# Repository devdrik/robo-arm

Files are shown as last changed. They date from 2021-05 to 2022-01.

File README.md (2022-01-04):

# robo arm

https://user-images.githubusercontent.com/67547895/148030076-b6884d7a-699d-42de-8d19-b7936f6b32be.mp4

This repo is all about the little robo arm. The community named it **Serworm Michael**, so that is his name now. The arm has a very simple structure, but still enough DoFs to make it a fun challenge to work with. The structure can be 3D printed. The servos are Dynamixel XL330-M288-T. There should be everything you need in this repo. If not, please let me know! 

The project is work in progress, but it already works. I am very happy, if you add features, refactor the code or point out bad practices. Feel free to open an issue, a pull-request or contact me.

You can find a more detailed (german) description here: [devdrik.de/robo-arm](https://devdrik.de/robo-arm/)

And here is a video about the desgin and assembly: https://youtu.be/1fdFsHWkn9U

## Material

You wont need much, but you need something for this robo. Here is a list:
* 1 Arduino MKR
* 1 DYNAMIXEL Shield for Arduino MKR
* 5 DYNAMIXEL-XL330-M288-T
* 1 Raspberry Pi
* USB-a to micro USB cable
* A 3D-Printer could help

Find product links here: [devdrik.de/hardware-von-serworm-michael](https://devdrik.de/hardware-von-serworm-michael/)

## Setup

### Arduino
Nothing to setup here. Just flash dynamixel_api from the code/arduino folder to your Arduino and you are all set.

### Python environment

You need a python3 environment with pip installed in order to get the robo arm to work. In that env you need to install [ikpy](https://github.com/Phylliade/ikpy). You only need ikpy, if you intend to use inverse kinematics.
```
pip install ikpy
```

### 3D prints

The files to print can be found in the cad section. They should be easy prints, nothing special here. 
You will need:
* 1 base.stl (clamp to table)
* 1 base_element.stl (screwed to base servo)
* 4 arm_element.stl

## Build the bot

Building the robo arm is very easy! 
Put a servo in the base, screw the base_element on that. Then screw the arm_elements to it one after another. done!
You can use the screws shipped with the servos.
Make sure to clamp the base to a table or something solid, otherwise the arm will fall :(

## Configuration

You need to define the serial device in ```main.py```. This device is the arduino with the API.

## Usage

There is not yet a GUI or any other interface. You need to open the main file and write some code in order to get results. The easiest way is to comment in an example. Usually you want to use the API of robo.py to interact with the arm and the API of inversekinematics.py to calculate the input (angles) for the robo API.

You can also use the `teachposition` function to get a little cli and teach the arm some positions and save those for later.

There might be some helpful (german) articles on my blog: [devdrik.de/robo-arm](https://devdrik.de/robo-arm/)

# HAVE FUN!

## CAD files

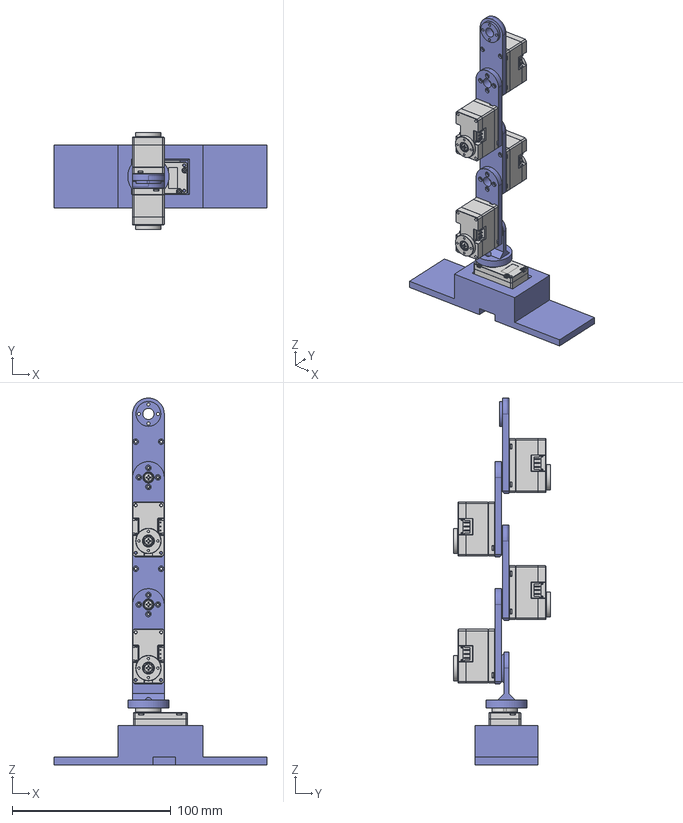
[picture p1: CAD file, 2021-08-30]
cad/roboArm.step
133.8 x 61.3 x 231.0 mm
ARM_4 x 4
DC15_A01_CASE_M_DUMMY x 5
DC15_A01_CASE_F_DUMMY x 5
DC15_A01_CASE_B_DUMMY x 5
DC15_A01_HORN_DUMMY x 5
DC15_A01_LED_CAP2_DUMMY x 5
PHS_1_7X20_5_DC10 x 20
BTS2_M2_6X8 x 10
DC15_A01_HORN_IDLE2_DUMMY x 5
DC15_A01_IDLE_CAP_DUMMY x 5
B3B-EH x 10

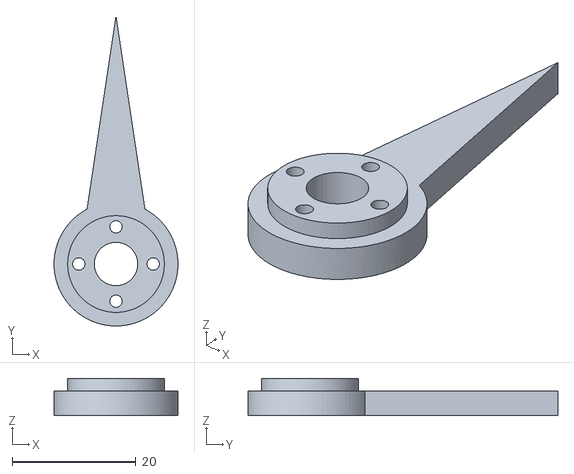
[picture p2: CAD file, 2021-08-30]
cad/clock_tip.stl
20.0 x 50.0 x 6.00

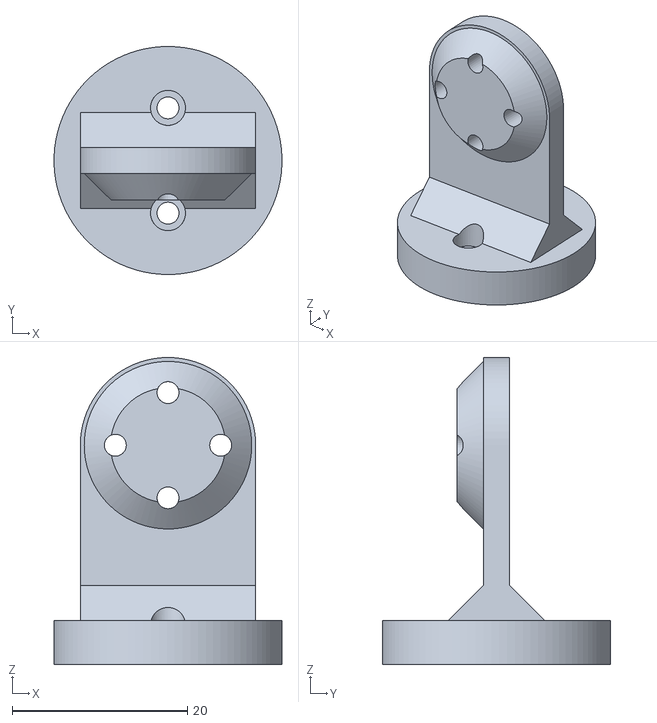
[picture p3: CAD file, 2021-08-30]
cad/base_element.stl
26.0 x 26.0 x 35.0

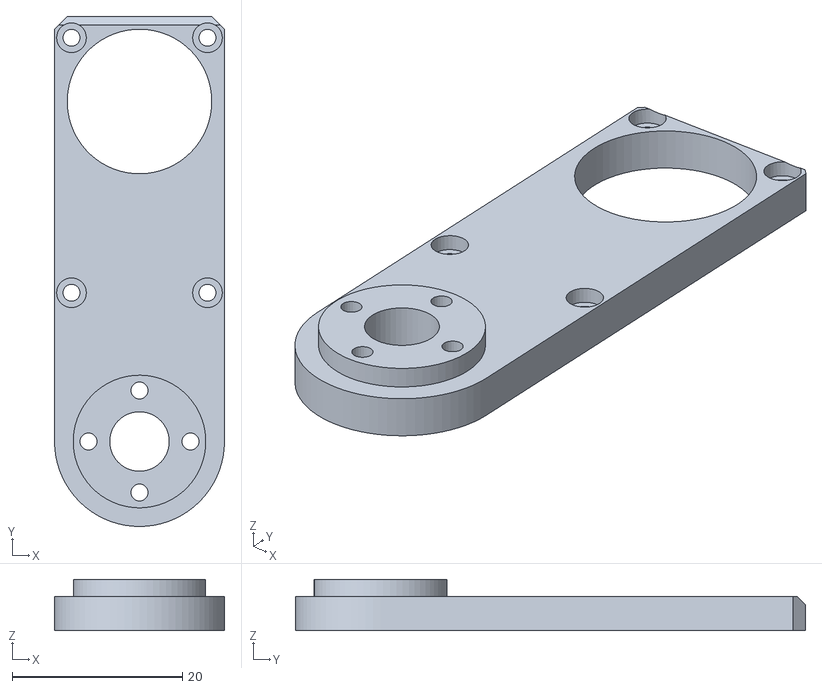
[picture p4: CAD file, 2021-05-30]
cad/arm_element.stl
20.0 x 60.0 x 6.00

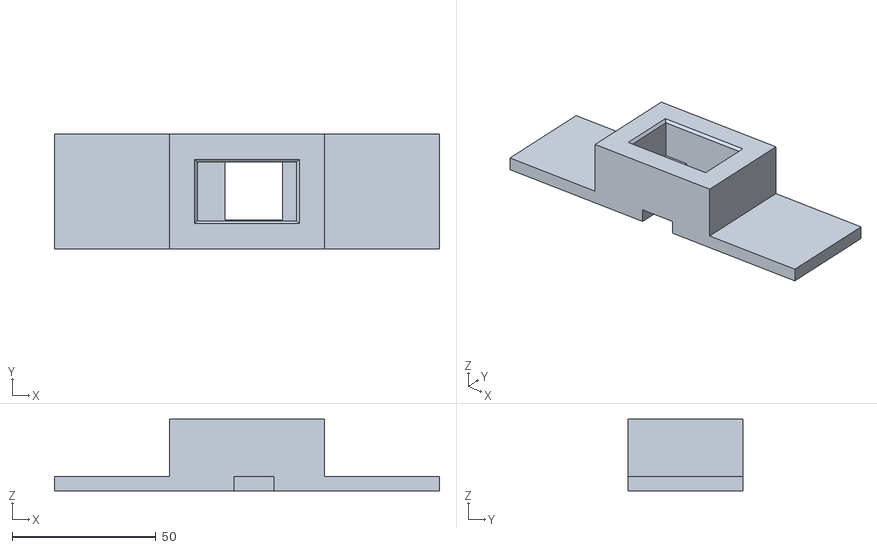
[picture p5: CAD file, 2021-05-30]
cad/base.stl
133.8 x 39.8 x 25.0

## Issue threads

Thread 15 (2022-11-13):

Building rotating  mini robot

ibnbax, 2022-11-13:
Can you make  rotating  robot  wich cant rotate phone for example and camera to take pictures
for the the phone  and how much ot will cost?

devdrik, 2022-11-16:
If you only want rotation around one axis, that should not be a problem, but you won't need a full arm for that either. If you want a full arm that is capable of holding a phone you are probably better off buying a commercial product.

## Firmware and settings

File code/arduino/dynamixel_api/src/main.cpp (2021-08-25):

/*******************************************************************************
* Copyright 2016 ROBOTIS CO., LTD.
*
* Licensed under the Apache License, Version 2.0 (the "License");
* you may not use this file except in compliance with the License.
* You may obtain a copy of the License at
*
*     http://www.apache.org/licenses/LICENSE-2.0
*
* Unless required by applicable law or agreed to in writing, software
* distributed under the License is distributed on an "AS IS" BASIS,
* WITHOUT WARRANTIES OR CONDITIONS OF ANY KIND, either express or implied.
* See the License for the specific language governing permissions and
* limitations under the License.
*******************************************************************************/

#include <DynamixelShield.h>

#define DEBUG_SERIAL Serial
#define DATA_SERIAL Serial
#define SERIAL_BAUD 115200

#define DEBUG false

const float DXL_PROTOCOL_VERSION = 2.0;
const uint8_t servosIDs[] = {0,1,2,3,4,11};
// the size of goalAngles should equal the highest servoID+1. This makes it easy to use the servoId as index to access goalAngles
float goalAngles[] = {0,0,0,0,0,0,0,0,0,0,0,0};

DynamixelShield dxl;


const char separator = ':';
const char msgEndChar = '\n';
#define FUNC_SET_ANGLE 1
#define FUNC_GET_ANGLE 2
#define FUNC_SET_ANGLE_FOUR 3
#define FUNC_SET_PROFILE_VELOCITY 4
#define FUNC_SET_PROFILE_VELOCITY_ALL 5
#define FUNC_HAS_REACHED_ANGLE 6
#define FUNC_SET_POSITION_MODE_ALL 7
#define FUNC_TORQUE_OFF_ALL 8
#define FUNC_IS_MOVING 9


//This namespace is required to use Control table item names
using namespace ControlTableItem;



void setAngle(u_int8_t servoId, float angle) {
  goalAngles[servoId] = angle;
  dxl.setGoalPosition(servoId, angle, UNIT_DEGREE);
}

float getAngle(u_int8_t servoId) {
  return dxl.getPresentPosition(servoId, UNIT_DEGREE);
}

void writeToControlTable(uint8_t servoID, uint8_t itemIdx, int32_t data) {
  dxl.torqueOff(servoID);
  dxl.writeControlTableItem(itemIdx, servoID, data);
  dxl.torqueOn(servoID);
}

void setProfileVelocity(uint8_t servoID, uint32_t velocity) {
  // 0-32767; 0 -> max speed
  writeToControlTable(servoID, PROFILE_VELOCITY, velocity);
}

void setProfileVelocityAll(uint32_t velocity) {
  for (uint8_t id : servosIDs) {
    writeToControlTable(id, PROFILE_VELOCITY, velocity);
  }
}

bool hasReachedGoalAngle(uint8_t servoId) {
  delay(50);
  int moving_status = dxl.readControlTableItem(MOVING_STATUS, servoId);
  // DEBUG_SERIAL.print("moving_status: ");
  // DEBUG_SERIAL.println(moving_status, BIN);
  int mask = 3;
  return (moving_status & mask) == 1;
  // float offset = 3;
  // float currentAngle = getAngle(servoId);
  // return currentAngle >= goalAngles[servoId] - offset &&
  //         currentAngle <= goalAngles[servoId] + offset;
}

void setOperatingMode(uint8_t servoID, uint8_t mode) {
  dxl.torqueOff(servoID);
  dxl.setOperatingMode(servoID, mode);
  dxl.torqueOn(servoID);
}

void torqueOff(uint8_t servoID) {
  dxl.torqueOff(servoID);
}

void floatToByte(byte* arr, float value) {
      long l = *(long*) &value;

      arr[0] = l & 0x00FF;
      arr[1] = (l >> 8) & 0x00FF;
      arr[2] = (l >> 16) & 0x00FF;
      arr[3] = l >> 24;
}

bool isMoving(uint8_t servoID) {
  int moving_status = dxl.readControlTableItem(MOVING_STATUS, servoID);
  int mask = 2;
  return (moving_status & mask) > 0;
}

void setup() {
  // put your setup code here, to run once:
  
  // For Uno, Nano, Mini, and Mega, use UART port of DYNAMIXEL Shield to debug.
  DATA_SERIAL.begin(SERIAL_BAUD);
  // while(!DEBUG_SERIAL);
  // if (DATA_SERIAL != DEBUG_SERIAL) {
  //   DEBUG_SERIAL.begin(SERIAL_BAUD);
  // }

  // Set Port baudrate to 57600bps. This has to match with DYNAMIXEL baudrate.
  dxl.begin(57600);
  // Set Port Protocol Version. This has to match with DYNAMIXEL protocol version.
  dxl.setPortProtocolVersion(DXL_PROTOCOL_VERSION);

  // Set all servos to position mode
  for(uint8_t servoID : servosIDs) {
    if(dxl.ping(servoID)) {
      dxl.torqueOff(servoID);
      dxl.setOperatingMode(servoID, OP_POSITION);
      dxl.writeControlTableItem(MOVING_THRESHOLD, servoID, 7);
      dxl.torqueOn(servoID);
      // DEBUG_SERIAL.print("Servo ");
      // DEBUG_SERIAL.print(servoID);
      // DEBUG_SERIAL.println(" set to Position Mode");
    } else {
      // DEBUG_SERIAL.print("Servo ");
      // DEBUG_SERIAL.print(servoID);
      // DEBUG_SERIAL.println(" not responding");
    }
  }

  // setProfileVelocity(0, 20);
  // setAngle(0, 1000);
  // while (!hasReachedGoalAngle(0))
  // {
  //   DEBUG_SERIAL.print("angle: ");
  //   DEBUG_SERIAL.println(getAngle(0));
  // }
  
  // DEBUG_SERIAL.print("done, angle: ");
  // DEBUG_SERIAL.println(getAngle(0));

  // setProfileVelocity(0, 20);
  // DEBUG_SERIAL.print("moving_threashold: ");
  // DEBUG_SERIAL.println(dxl.readControlTableItem(MOVING_THRESHOLD, 0));
  // setAngle(0, 20);
  // hasReachedGoalAngle(0);
  // delay(20);
  // hasReachedGoalAngle(0);
  // delay(20);
  // hasReachedGoalAngle(0);
  // delay(20);
  // hasReachedGoalAngle(0);
  // delay(20);
  // hasReachedGoalAngle(0);
  // delay(20);
  // hasReachedGoalAngle(0);
  // delay(20);
  // hasReachedGoalAngle(0);
  // delay(20);
  // hasReachedGoalAngle(0);
  // delay(20);
  // hasReachedGoalAngle(0);
  // delay(20);
  // hasReachedGoalAngle(0);
  // delay(20);
  // hasReachedGoalAngle(0);
  // delay(20);
  // hasReachedGoalAngle(0);
  // delay(20);
  // hasReachedGoalAngle(0);
  // delay(20);
  // hasReachedGoalAngle(0);
  // delay(20);
  // hasReachedGoalAngle(0);
  // delay(20);
  // hasReachedGoalAngle(0);
  // delay(20);
  // hasReachedGoalAngle(0);
  // delay(20);
  // hasReachedGoalAngle(0);
  // delay(20);
  // hasReachedGoalAngle(0);
  // delay(20);
  // hasReachedGoalAngle(0);
  // delay(20);
  // hasReachedGoalAngle(0);
  // delay(20);
  // hasReachedGoalAngle(0);
  // delay(20);
  // hasReachedGoalAngle(0);
  // delay(20);
  // hasReachedGoalAngle(0);
  // delay(20);
  // hasReachedGoalAngle(0);
  // delay(20);
  // // DEBUG_SERIAL.print("hasReached2: ");
  // // DEBUG_SERIAL.println(hasReachedGoalAngle(0));
  // // delay(100);
  // // DEBUG_SERIAL.print("hasReached3: ");
  // // DEBUG_SERIAL.println(hasReachedGoalAngle(0));
  // delay(10000);
  // DEBUG_SERIAL.println("delayed 10");
  // hasReachedGoalAngle(0);
  // // DEBUG_SERIAL.print("hasReached4: ");
  // // DEBUG_SERIAL.println(hasReachedGoalAngle(0));
  // // while (!hasReachedGoalAngle(0))
  // //   DEBUG_SERIAL.println("Im looping");
  // // {
  // // DEBUG_SERIAL.print("hasReached after: ");
  // // DEBUG_SERIAL.println(hasReachedGoalAngle(0));

  // delay(500);
  // setAngle(0, 1);
  // while (!hasReachedGoalAngle(0))
  // {
  //   DEBUG_SERIAL.print("angle: ");
  //   DEBUG_SERIAL.println(getAngle(0));
  // }

  // DEBUG_SERIAL.print("done, angle: ");
  // DEBUG_SERIAL.println(getAngle(0));

  
}
// FUNC:PARAM1:PARAMX\n

void loop() {

  if ( DATA_SERIAL.available() > 0 ) {
    uint8_t function = DATA_SERIAL.readStringUntil(separator).toInt();
    uint8_t id;
    float angle;
    uint32_t profileVelocity;

    switch (function)
    {
    case FUNC_SET_ANGLE:
      // FUNC:ID:ANGLE
      id = DATA_SERIAL.readStringUntil(separator).toInt();
      angle = DATA_SERIAL.readStringUntil(msgEndChar).toFloat();
      // Serial.print("Angle read and converted from string: ");
      // Serial.println(angle);
      setAngle(id, angle);
      break;
    
    case FUNC_GET_ANGLE:
      // FUNC:ID
      id = DATA_SERIAL.readStringUntil(msgEndChar).toInt();
      angle = getAngle(id);
      byte angleBytes[4];
      floatToByte(angleBytes, angle);
      DATA_SERIAL.write(angleBytes, 4);
      break;

    case FUNC_SET_ANGLE_FOUR:
    // FUNC:ANGLE1:ANGLE2:ANGLE3:ANGLE4
      setAngle(1, DATA_SERIAL.readStringUntil(separator).toFloat());
      setAngle(2, DATA_SERIAL.readStringUntil(separator).toFloat());
      setAngle(3, DATA_SERIAL.readStringUntil(separator).toFloat());
      setAngle(4, DATA_SERIAL.readStringUntil(msgEndChar).toFloat());
      break;

    case FUNC_SET_PROFILE_VELOCITY:
      // FUNC:ID:VELOCITY
      id = DATA_SERIAL.readStringUntil(separator).toInt();
      profileVelocity = DATA_SERIAL.readStringUntil(msgEndChar).toInt();
      setProfileVelocity(id, profileVelocity);
      break;

    case FUNC_SET_PROFILE_VELOCITY_ALL:
      // FUNC:VELOCITY
      profileVelocity = DATA_SERIAL.readStringUntil(msgEndChar).toInt();
      setProfileVelocityAll(profileVelocity);
      break;

    case FUNC_HAS_REACHED_ANGLE:
      // FUNC:ID
      id = DATA_SERIAL.readStringUntil(msgEndChar).toInt();
      bool hasReachedAngle;
      hasReachedAngle = hasReachedGoalAngle(id);
      byte hasReached;
      hasReached = hasReachedAngle ? (byte) 1 : (byte) 0;
      DATA_SERIAL.write(hasReached);
      break;

    case FUNC_SET_POSITION_MODE_ALL:
      // FUNC:ID
      id = DATA_SERIAL.readStringUntil(msgEndChar).toInt();
      setOperatingMode(id, OP_POSITION);
      break;

    case FUNC_TORQUE_OFF_ALL:
      // FUNC:ID
      id = DATA_SERIAL.readStringUntil(msgEndChar).toInt();
      torqueOff(id);
      break;

    case FUNC_IS_MOVING:
      // FUNC:ID
      id = DATA_SERIAL.readStringUntil(msgEndChar).toInt();
      byte isMovingByte; 
      isMovingByte = (byte)(isMoving(id) ? 1 : 0);
      DATA_SERIAL.write(isMovingByte);
      break;

    default:
      break;
    }
  }

}

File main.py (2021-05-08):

from imageprocessor import ImageProcessor
from inversekinematics import InverseKinematics
from robo import Robo
import time
import cv2
from imutils.video import VideoStream
import imutils
from myutils import map
import math
from myLogger import log
from servo import Servo
from adafruit_servokit import ServoKit
from dynamixel import Dynamixel

import serial
ser = serial.Serial('/dev/ttyACM0', 115200, timeout=1)
ser.flush()

# kit = ServoKit(channels=16)
# servos = [Servo(0, (-180, 180), kit, lock), Servo(1, (-90, 90), kit, lock,5), Servo(2, (-90, 90), kit, lock, -5, True), Servo(3, (-90, 90), kit, lock,7), Servo(4, (-90, 90), kit, lock, True)]
servos = [Dynamixel(0, ser), Dynamixel(1, ser), Dynamixel(2, ser), Dynamixel(3, ser), Dynamixel(4, ser)]
robo = Robo(servos)

def simpleMovementExample():
    for i in range(-60,60,10):
        robo.moveToRaw([i,0,50])
        # time.sleep(0.5)

def myMove():
    path = [[-70, 0, 20],[-70, 0, 60],[0, 0, 60],[70, 0, 60],[70, 0, 20]]
    for point in path:
        robo.moveToRaw(point)

def moveWithCV(showMovie=False):
    ip = ImageProcessor()
    vid = VideoStream(src=0).start()
    time.sleep(2.0)
    while True:
        frame = vid.read()
        if frame is None:
            break
        frame = imutils.resize(frame, width=600)
        if showMovie:
            if ip.contour is not None:
                cv2.drawContours(frame, [ip.contour], 0, (0,255,0),3)

        x,y = ip.getPositionFromFrame(frame)
        if showMovie:
            cv2.putText(frame,"x: {}, y: {}".format(math.floor(x),math.floor(y)),(100,50),cv2.FONT_HERSHEY_SIMPLEX,2,(255,255,255),3)
            cv2.imshow("Test", frame)
            key = cv2.waitKey(1) & 0xFF
            if key == ord("q"):
                robo.chill()
                break
        # log("x: {}, y: {}".format(x,y),'ERR')

        # robo.moveToRaw([x,-30,y])
        # time.sleep(0.1)

kinematics = InverseKinematics()
def getAngles(pos):
    angles, outOfRange = kinematics.getAnglesRaw(pos)
    return angles

def getCoordinatesFrom(radius, mx, my, mz, alpha):
    y = my
    x = mx + math.cos(math.radians(alpha)) * radius
    z = mz + math.sin(math.radians(alpha)) * radius
    log("x={}, y={}, z={}".format(x,y,z))
    return [x,y,z]

def moveCircle():
    stepDegree = 12
    r = 20
    mx = -40
    my = -40
    mz = 30
    angles = []
    offset = 90
    for alpha in range( 0 + offset, 360 + offset, stepDegree):
        coordinates = getCoordinatesFrom(r,mx,my,mz,alpha)
        angle = getAngles(coordinates)
        robo.setAngles(angle)

def createCircleFile():
    stepDegree = 6
    r = 30
    mx = 20
    mz = 50
    angles = []
    for alpha in range( 0, 360, stepDegree):
        [x,y,z] = getCoordinatesFrom(r,mx,my,mz,alpha)
        angle, outOfRange = kinematics.getAnglesRaw([x,y,z])
        if not outOfRange:
            angles.append(angle)
    
    fname = "circle_r{}_step{}_mx{}_mz{}".format(r,stepDegree,mx,mz)
    with open(fname, "w") as f:
        for angle in angles:
            f.write("{},{},{},{},{}\n".format(angle[0],angle[1],angle[2],angle[3],angle[4]))

def readAngles():
    r=40
    step=2
    mx=0
    mz=50
    fname = "circle_r{}_step{}_mx{}_mz{}".format(r,step,mx,mz)
    with open(fname) as f:
        lines = f.readlines()
    angles = []
    # print(lines)
    for line in lines:
        lineValues = []
        for value in line.split(','):
            if value.endswith("\n"):
                value=value[:-2]
            lineValues.append(float(value))
        angles.append(lineValues)
    return angles

def getAnglesFromFile(fname):
    with open(fname) as f:
        lines = f.readlines()
    angles = []
    # print(lines)
    for line in lines:
        lineValues = []
        for value in line.split(','):
            if value.endswith("\n"):
                value=value[:-2]
            lineValues.append(float(value))
        angles.append(lineValues)
    return angles
        
def auroraMoves():
    # robo.setVelocity(100)
    robo.moveToRawBlocking([30,10,60])
    time.sleep(1.0)
    # robo.moveToRawBlocking([120,-30,30])
    # time.sleep(2.0)
    robo.setAnglesBlocking([-120, -45, 45, 45, 45])
    time.sleep(1.0)
    robo.setAnglesBlocking([-167, 1, 90, 80, -70])

def wafe():
    # for angle in range(-50, 50, 1):
    #     robo.setAngles([0, -angle, angle, -angle, angle])
    while True:
        for angle in range(-29, 30, 1):
            robo.setAngles([0, -angle, angle*1.1, -angle*1.4, angle*2])
        for angle in range(29, -30, -1):
            robo.setAngles([0, -angle, angle*1.1, -angle*1.4, angle*2])

def dance():
    # for angle in range(-50, 50, 1):
    #     robo.setAngles([0, -angle, angle, -angle, angle])
    # while True:
    #     for angle in range(0, 60, 1):
    #         robo.setAngles([0, angle, 2*angle, angle, 0])
    #     for angle in range(59, 1, -1):
    #         robo.setAngles([0, angle, 2*angle, angle, 0])
    #     for angle in range(0, 60, 1):
    #         robo.setAngles([0, 0, angle, 2*angle, angle])
    #     for angle in range(59, 1, -1):
    #         robo.setAngles([0, 0, angle, 2*angle, angle])
    #     for angle in range(0, 60, 1):
    #         robo.setAngles([0, 0, 0, angle, 2*angle])
    #     for angle in range(59, 1, -1):
    #         robo.setAngles([0, 0, 0, angle, 2*angle])
    velocity = 100
    while True:
        robo.setVelocity(velocity)

        robo.setVelocityForIndex(2, velocity*2)
        angle = 60
        robo.setAnglesBlocking([0, angle, 2*angle, angle, 0])
        angle = 0
        robo.setAnglesBlocking([0, angle, 2*angle, angle, 0])

        robo.setVelocityForIndex(2, velocity)
        robo.setVelocityForIndex(3, velocity*2)
        angle = 60
        robo.setAnglesBlocking([0, 0, angle, 2*angle, angle])
        angle = 0
        robo.setAnglesBlocking([0, 0, angle, 2*angle, angle])
        
        robo.setVelocityForIndex(3, velocity)
        robo.setVelocityForIndex(4, velocity*2)
        angle = 60
        robo.setAnglesBlocking([0, 0, 0, angle, 2*angle])
        angle = 0
        robo.setAnglesBlocking([0, 0, 0, angle, 2*angle])

        robo.setVelocityForIndex(1, velocity)
        robo.setVelocityForIndex(2, velocity*2)
        robo.setVelocityForIndex(3, velocity*2)
        robo.setVelocityForIndex(4, velocity*2)
        angle = 60
        robo.setAnglesBlocking([0, angle, 2*angle, 2*angle, 2*angle])
        angle = 0
        robo.setAnglesBlocking([0, angle, 2*angle, 2*angle, 2*angle])

        robo.setVelocity(velocity)
        break

def saveToFile(fname, angles):
    with open(fname, "w") as f:
        for angle in angles:
            f.write("{},{},{},{},{}\n".format(angle[0],angle[1],angle[2],angle[3],angle[4]))
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

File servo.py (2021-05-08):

import RPi.GPIO as GPIO
import myutils
from myLogger import log
import time
from adafruit_servokit import ServoKit
from IServo import IServo

class Servo(IServo):

    # kit = ServoKit(channels=16)

    def __init__(self, pin, bounds, servoKit, lock, offset=0, inverted=False):
        self.bounds = bounds
        self.inverted = False
        self.servo = servoKit.servo[pin]
        self.pin = pin
        self.lock = lock
        self.offset = offset
        # self.offset = 0

    def __del__(self):
        pass

    def getCorrectedAngle(self, angle):
        if self.inverted:
            angle = -angle
        angle += self.offset
        if angle > self.bounds[1]:
            angle = self.bounds[1]
            log("angle of servo {} out of bounds. angle is {}".format(self.pin, angle),"ERR")
        if angle < self.bounds[0]:
            angle = self.bounds[0]
            log("angle of servo {} out of bounds. angle is {}".format(self.pin, angle),"ERR")
        newAngle = myutils.map(angle, self.bounds[0], self.bounds[1], 0, 180)
        return newAngle

    def getAngle(self):
        return myutils.map(self.servo.angle, 0, 180, self.bounds[0], self.bounds[1])

    def setAngle(self, angle):
        newAngle = self.getCorrectedAngle(angle)
        # log("newAngle: {}".format(newAngle))
        self.servo.angle = newAngle

    def chill(self):
        pass

    def setAngleSmooth(self, angle, controlTimeInMs):
        # log("setting angle: {}, controlTime: {}".format(angle, controlTimeInMs))
        testStartTime = time.time()
        correctedAngle = self.getCorrectedAngle(angle)
        incrementAngle = 2 # smaller one doesn't work - the actual increment is for some reason smaller than the set increment

        steps=0
        counter = 0
        deltaAngle = abs(correctedAngle - self.servo.angle)
        # log("deltaAnlge: {}".format(deltaAngle))
        if deltaAngle >= incrementAngle:
            direction = 1 if correctedAngle > self.servo.angle else -1 
            steps = deltaAngle / incrementAngle
            incrementTime = abs(controlTimeInMs) / steps if steps > 1 else controlTimeInMs
            
            startTime = time.time()
            while self.servo.angle < correctedAngle and direction is 1 or self.servo.angle > correctedAngle and direction is -1:
                now = time.time()
                if now >= startTime + incrementTime / 1000:
                    # log("I am doing something {}".format(self.pin), "OK")
                    counter += 1
                    startTime = now
                    if self.servo.angle <= 180 - incrementAngle and direction is 1 or self.servo.angle >= incrementAngle and direction is -1:
                        angleBefore = self.servo.angle
                        self.servo.angle += direction * incrementAngle
                        # here comes a hack to compensate the wrong increment angle
                        steps = deltaAngle / abs(self.servo.angle - angleBefore)
                        incrementTime = abs(controlTimeInMs) / steps if steps > 1 else incrementTime
                    else:
                        if direction is 1:
                            self.servo.angle = 180
                        if direction is -1:
                            self.servo.angle = 0
                        break
        # if time.time()-testStartTime > (controlTimeInMs - 100) / 1000:
            # log("Time to set angle: {}".format(time.time()-testStartTime))
            # log("steps proposed: {}, steps used: {}".format(steps, counter))

    def setAngleSmooth2(self, angle, controlTimeInMs):
        # print("setting angle of {} to {}".format(self.pin, angle))
        correctedAngle = self.getCorrectedAngle(angle)
        incrementAngle = 1 # smaller one doesn't work - the actual increment is for some reason smaller than the set increment

        steps=0
        counter = 0
        with self.lock:
            currentAngle = self.servo.angle
            
        deltaAngle = abs(correctedAngle - currentAngle)
        # log("deltaAnlge: {}".format(deltaAngle))
        steps = deltaAngle / incrementAngle
        if steps >= 1:
            direction = 1 if correctedAngle > currentAngle else -1 
            incrementTime = controlTimeInMs / steps / 1000
            while currentAngle < correctedAngle and direction is 1 or currentAngle > correctedAngle and direction is -1:
                nextAngle = currentAngle + direction * incrementAngle
                nextAngle = 0 if nextAngle < 0 else nextAngle
                nextAngle = 180 if nextAngle > 180 else nextAngle
                with self.lock:
                    self.servo.angle = nextAngle
                    currentAngle = self.servo.angle
                # print("current angle of {} is {}".format(self.pin, currentAngle))
                time.sleep(incrementTime)

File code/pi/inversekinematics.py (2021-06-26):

from ikpy.chain import Chain
from ikpy.link import OriginLink, URDFLink
import math
import myutils
from myLogger import log
import time


'''
InverseKinematics calculates the inverse kinamatics
You need to define your robot in the init function 
Beware: There are some hard-coded values here and the code might be brittle!
'''
class InverseKinematics():

    def __init__(self):
        # Second robo, with dynamixel
        self.armLength = 4
        self.smallArmLength = 4
        lim = math.pi/4
        # lim = 7*math.pi/9
        self.chain = Chain(name='arm', links=[
            OriginLink(
            ),
            URDFLink(
            name="base",
            translation_vector=[0, 0, 0],
            orientation=[0, 0, 0],
            rotation=[0, 0, 1],
            bounds=(-math.pi,math.pi)
            ),
            URDFLink(
            name="first",
            translation_vector=[0, 0, 0],
            orientation=[0, 0, 0],
            rotation=[0, 1, 0],
            bounds=(-lim,lim)
            ),
            URDFLink(
            name="second",
            translation_vector=[0, 0, self.armLength],
            orientation=[0, 0, 0],
            rotation=[0, -1, 0],
            bounds=(-lim,lim)
            ),
            URDFLink(
            name="third",
            translation_vector=[0, 0, self.armLength],
            orientation=[0, 0, 0],
            rotation=[0, 1, 0],
            bounds=(-lim,lim)
            ),
            URDFLink(
            name="fourth",
            translation_vector=[0, 0, self.armLength],
            orientation=[0, 0, 0],
            rotation=[0, -1, 0],
            bounds=(-lim,lim)
            ),
            URDFLink(
            name="tip",
            translation_vector=[0, 0, self.smallArmLength],
            orientation=[0, 0, 0],
            rotation=[0, 0, 0],
            )
        ])
        self.xMin = -3*self.armLength - self.smallArmLength
        self.xMax = 3*self.armLength + self.smallArmLength
        self.yMin = -3*self.armLength - self.smallArmLength
        self.yMax = 3*self.armLength + self.smallArmLength
        self.zMin = 0
        self.zMax = 3*self.armLength + self.smallArmLength
        self.radToDegreeFactor = 180 / math.pi
        self.degreeToRadFactor = math.pi / 180
        self.numberOfLinks = len(self.chain.links)


    # def __init__(self):
    #     # First robo, with MG995 Servos
    #     self.armLength = 10
    #     self.smallArmLength = 5
    #     self.chain = Chain(name='arm', links=[
    #         OriginLink(
    #         ),
    #         URDFLink(
    #         name="base",
    #         translation_vector=[0, 0, 0],
    #         orientation=[0, 0, 0],
    #         rotation=[0, 0, 1],
    #         bounds=(-math.pi,math.pi)
    #         ),
    #         URDFLink(
    #         name="first",
    #         translation_vector=[0, 0, 0],
    #         orientation=[0, 0, 0],
    #         rotation=[0, 1, 0],
    #         bounds=(-4*math.pi/9,4*math.pi/9)
    #         ),
    #         URDFLink(
    #         name="second",
    #         translation_vector=[0, 0, self.armLength],
    #         orientation=[0, 0, 0],
    #         rotation=[0, -1, 0],
    #         bounds=(-4*math.pi/9,4*math.pi/9)
    #         ),
    #         URDFLink(
    #         name="third",
    #         translation_vector=[0, 0, self.armLength],
    #         orientation=[0, 0, 0],
    #         rotation=[0, 1, 0],
    #         bounds=(-4*math.pi/9,4*math.pi/9)
    #         ),
    #         URDFLink(
    #         name="fourth",
    #         translation_vector=[0, 0, self.armLength],
    #         orientation=[0, 0, 0],
    #         rotation=[0, -1, 0],
    #         bounds=(-4*math.pi/9,4*math.pi/9)
    #         ),
    #         URDFLink(
    #         name="tip",
    #         translation_vector=[0, 0, self.smallArmLength],
    #         orientation=[0, 0, 0],
    #         rotation=[0, 0, 0],
    #         )
    #     ])
    #     self.xMin = -3*self.armLength - self.smallArmLength
    #     self.xMax = 3*self.armLength + self.smallArmLength
    #     self.yMin = -3*self.armLength - self.smallArmLength
    #     self.yMax = 3*self.armLength + self.smallArmLength
    #     self.zMin = 0
    #     self.zMax = 3*self.armLength + self.smallArmLength
    #     self.radToDegreeFactor = 180 / math.pi
    #     self.degreeToRadFactor = math.pi / 180
    #     self.numberOfLinks = len(self.chain.links)

    def __del__(self):
        pass

    def getPosition(self, angles, allLinks=False):
        anglesRad = []
        if not allLinks:
            anglesRad.append(0)
        for angle in angles:
            anglesRad.append(angle * self.degreeToRadFactor)
        if not allLinks:
            anglesRad.append(0)
        # print("anglesRad: {}".format(anglesRad))
        calcPos = self.chain.forward_kinematics(anglesRad)[:3,3]
        calcPosPerc = []
        calcPosPerc.append(myutils.map(calcPos[0],self.xMin,self.xMax,-100,100))
        calcPosPerc.append(myutils.map(calcPos[1],self.yMin,self.yMax,-100,100))
        calcPosPerc.append(myutils.map(calcPos[2],self.zMin,self.zMax,0,100))
        return calcPosPerc
        

    def getAngles(self, pos):
        if pos[0] == 0:
            pos[0] = 0.01 
        if pos[1] == 0:
            pos[1] = 0.01 
        if pos[2] == 0:
            pos[2] = 0.01 
        pos[0] = myutils.map(pos[0], 0, 100, self.xMin, self.xMax)
        pos[1] = myutils.map(pos[1], 0, 100, self.yMin, self.yMax)
        pos[2] = myutils.map(pos[2], 0, 100, self.zMin, self.zMax)
        anglesRad = self.chain.inverse_kinematics(pos)
        angles = anglesRad * self.radToDegreeFactor
        
        calcPos = self.chain.forward_kinematics(anglesRad)[:3,3]
        calcPosPerc = self.getPosition(angles, True)
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

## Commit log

2021-05-08 Chore/restructure project (#2)
    * created subdir for raspberry pi code
    * restructured pi files
    * excluded .pyc files
2021-05-19 Feature/teach positions (#4)
    * removed .vscode from project
    * added functions needed to teach posiiton
    * added position teaching feature and mini cli
    * added working version of readng bytes over serial
    * updated getangles to send float casted to bytes
    * just some nonsense jh
    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
2021-05-30 added step and stl files (#7)
    [arm_element.stl, base.stl, base_element.stl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]
2021-05-30 Feature/update readme (#8)
    * first readme version with some information
    * added serial device config section
    * added more infos, should work as first version
2021-06-21 Feature/add velocity to saved files (#9)
    * added velocity handling in filehander
    * handle velocity in files in robocli moves
    * fixed typobug
    * removed test movefile
    * added velocity input menu
    [filehandler.py, robocli.py]
2021-06-26 Chore/refactor robo cli (#10)
    * reafactored cli, added hints to ik and main for serial device
    * minor text changes
2021-08-25 switched hasReachedAngle to use hasReachedAngle function from arduino interface
2021-08-25 Chore/decouple actions from cli (#11)
    * decoupled actions from cli
    * fixed bugs and error
    [actionHandler.py, main.py, robocli.py]
2021-08-26 fixed bug, clear actions works now
    [actionHandler.py, robocli.py]
2021-08-30 Bugfix/fix base element overlap (#14)
    * fixed overlap of base and arm
    * also sneaked in the tip for the clock in this bugfix branch 😎
    [base_element.stl, clock_tip.stl, roboArm.step]
